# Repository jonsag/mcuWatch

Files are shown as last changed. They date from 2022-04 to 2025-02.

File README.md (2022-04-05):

# mcuWatch

A watch based on an ATmega32P or an ESP8266 module with an RTC clock and a TFT screen  

## Links

### Arduino

[Tutorial on how to use DS3231 RTC Module](https://create.arduino.cc/projecthub/mdraber/tutorial-on-how-to-use-ds3231-rtc-module-e12b38)  
[The ST7735 TFT with arduino](https://www.electronics-lab.com/project/using-st7735-1-8-color-tft-display-arduino/)  
[Arduino DS3231 Real Time Clock With Color TFT](https://www.instructables.com/Arduino-DS3231-Real-time-clock-with-color-TFT/)  

### ESP8266

[ESP8266 pinout reference and how to use GPIO pins](https://microcontrollerslab.com/esp8266-pinout-reference-gpio-pins/)  
[ESP8266 Pinout Reference: Which GPIO pins should you use?](https://randomnerdtutorials.com/esp8266-pinout-reference-gpios/)  
[NodeMCU GPIO with Arduino IDE](https://www.electronicwings.com/nodemcu/nodemcu-gpio-with-arduino-ide)  

[Connecting a 1.77 inch TFT LCD screen to ESP8266](http://gogs.info/blog/2020/03/connecting-177-inch-TFT-LCD-screen-ESP8266/)  
[NodeMCU and 1.8" SPI ST7735 Display](https://www.instructables.com/NodeMCU-and-18-SPI-ST7735-Display/)  
[Interfacing ESP8266 NodeMCU with ST7735 TFT](https://simple-circuit.com/esp8266-nodemcu-st7735s-tft/)  
[ESP8266 NodeMCU Internet Clock with ST7735 TFT](https://simple-circuit.com/esp8266-nodemcu-st7735-tft-internet-clock/)  

### Libraries

[DS3231](https://github.com/NorthernWidget/DS3231)  
[Adafruit GFX Library](https://github.com/adafruit/Adafruit-GFX-Library)  
[Adafruit SSD1306](https://github.com/adafruit/Adafruit_SSD1306)  

#### Tiny/Compact TFT Graphics Library

[Tiny TFT Graphics Library](http://www.technoblogy.com/show?L6I)  

[Compact TFT Graphics Library](http://www.technoblogy.com/show?2LMJ)
[Source](https://github.com/technoblogy/compact-tft-graphics-library)

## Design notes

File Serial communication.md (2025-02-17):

# Serial Communication HowTo

## Find the device

>$ dmesg

    ...
    [256966.875728] usb 1-1.4: ch341-uart converter now attached to ttyUSB0

## CLI software

### picocom

[picocom @ github](https://github.com/npat-efault/picocom)  
[picocom man page](https://linux.die.net/man/8/picocom)  

Connect  
>$ picocom -b 115200 /dev/ttyUSB0 --omap crcrlf  

    picocom v3.1
    ...
    Type [C-a] [C-h] to see available commands
    Terminal ready

Turn on local echo  
> [Ctrl+a] [Ctrl+c]

    *** local echo: yes ***

Exit  

> [Ctrl+a] [Ctrl+x]

    Terminating...
    Thanks for using picocom

### cu

[cu @ github](https://github.com/nedko/cu)  
[cu man page](https://linux.die.net/man/1/cu)  

A simple serial monitor  

>$ cu -l /dev/ttyACM0 -s 9600

Exit
> ~. (tilde dot)  

### screen

[screen man page](https://linux.die.net/man/1/screen)  

Connect  

>$ screen /dev/ttyUSB0 9600

### minicom

[minicom @ github](https://github.com/Distrotech/minicom)  
[minicom man page](https://linux.die.net/man/1/minicom)  

### GUI software

[CuteCom](http://cutecom.sourceforge.net/)  

## ESP-01

### If you have AT firmware, for example an ESP-01

Check for AT firmware  
>AT

    OK

Check version  

>AT+GMR

    AT version:1.7.4.0(May 11 2020 19:13:04)
    SDK version:3.0.4(9532ceb)
    compile time:May 27 2020 10:12:17
    Bin version(Wroom 02):1.7.4
    OK

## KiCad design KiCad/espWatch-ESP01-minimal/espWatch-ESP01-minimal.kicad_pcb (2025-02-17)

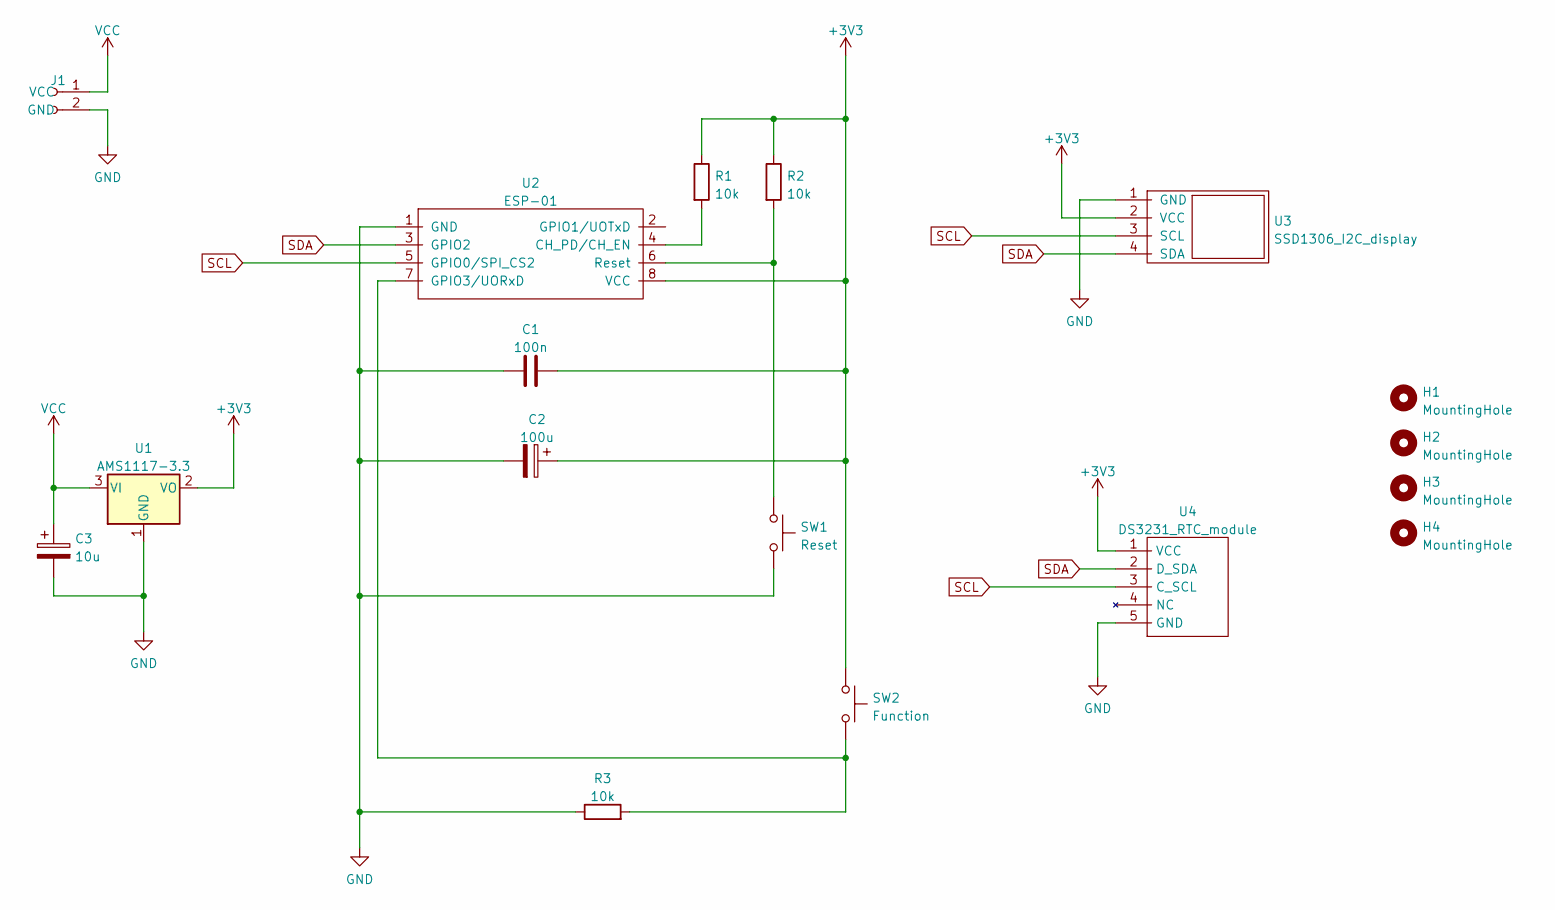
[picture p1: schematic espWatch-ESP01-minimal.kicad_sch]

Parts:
C1: 100n; C_Disc_D3.0mm_W1.6mm_P2.50mm_larg
C2: 100u; CP_Radial_D5.0mm_P2.00mm_larger
C3: 10u; CP_Radial_D5.0mm_P2.00mm_larger
H1, H2, H3, H4: MountingHole; MountingHole_3.2mm_M3
J1: 2-pin_power_input_header; 2-pin_power_input_header_larger_pads
R1, R2, R3: 10k; R_Axial_DIN0207_L6.3mm_D2.5mm_P10.16mm_Horizontal_larger_pa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
SW1: Reset; SW_PUSH_6mm_large
SW2: Function; SW_PUSH_6mm_large
U1: AMS1117-3.3; SOT-223-3_TabPin2
U2: ESP-01; ESP-01_w_pin_socket_large
U3: SSD1306_I2C_display; SSD1306_I2C_0.96_OLED_display_large
U4: DS3231_RTC_module; DS3231_RTC_module_large

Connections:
+3V3: C1.2, C2.1, R1.1, R2.1, SW2.1, U1.2 (VO), U2.8 (VCC), U3.2 (VCC), U4.1 (VCC)
GND: C1.1, C2.2, C3.2, J1.2 (GND), R3.1, SW1.2, U1.1 (GND), U2.1 (GND), U3.1 (GND), U4.5 (GND)
unnamed: R1.2, U2.4 (CH_PD/CH_EN)
unnamed: R2.2, SW1.1, U2.6 (Reset)
unnamed: R3.2, SW2.2, U2.7 (GPIO3/UORxD)
SCL: U2.5 (GPIO0/SPI_CS2), U3.3 (SCL), U4.3 (C_SCL)
SDA: U2.3 (GPIO2), U3.4 (SDA), U4.2 (D_SDA)
VCC: C3.1, J1.1 (VCC), U1.3 (VI)

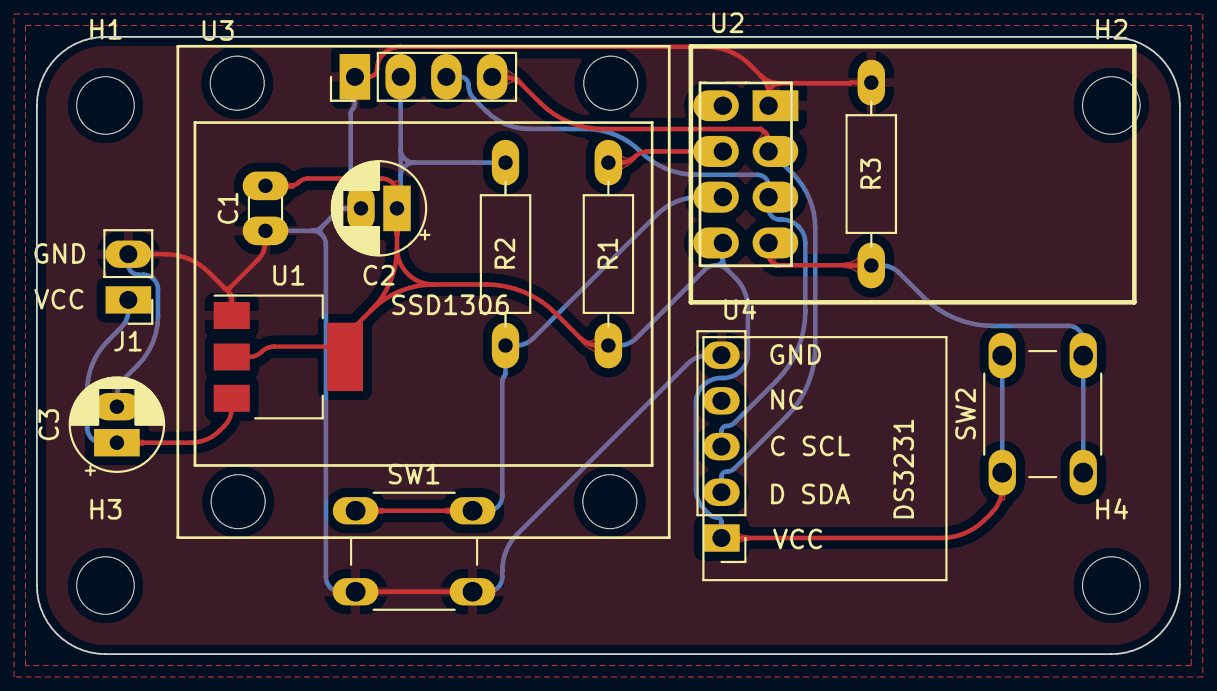
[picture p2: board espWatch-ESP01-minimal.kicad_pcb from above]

Board: 2 copper layers, 63.5 x 34.3 mm, 17 parts (0 on the bottom side), 8 nets.

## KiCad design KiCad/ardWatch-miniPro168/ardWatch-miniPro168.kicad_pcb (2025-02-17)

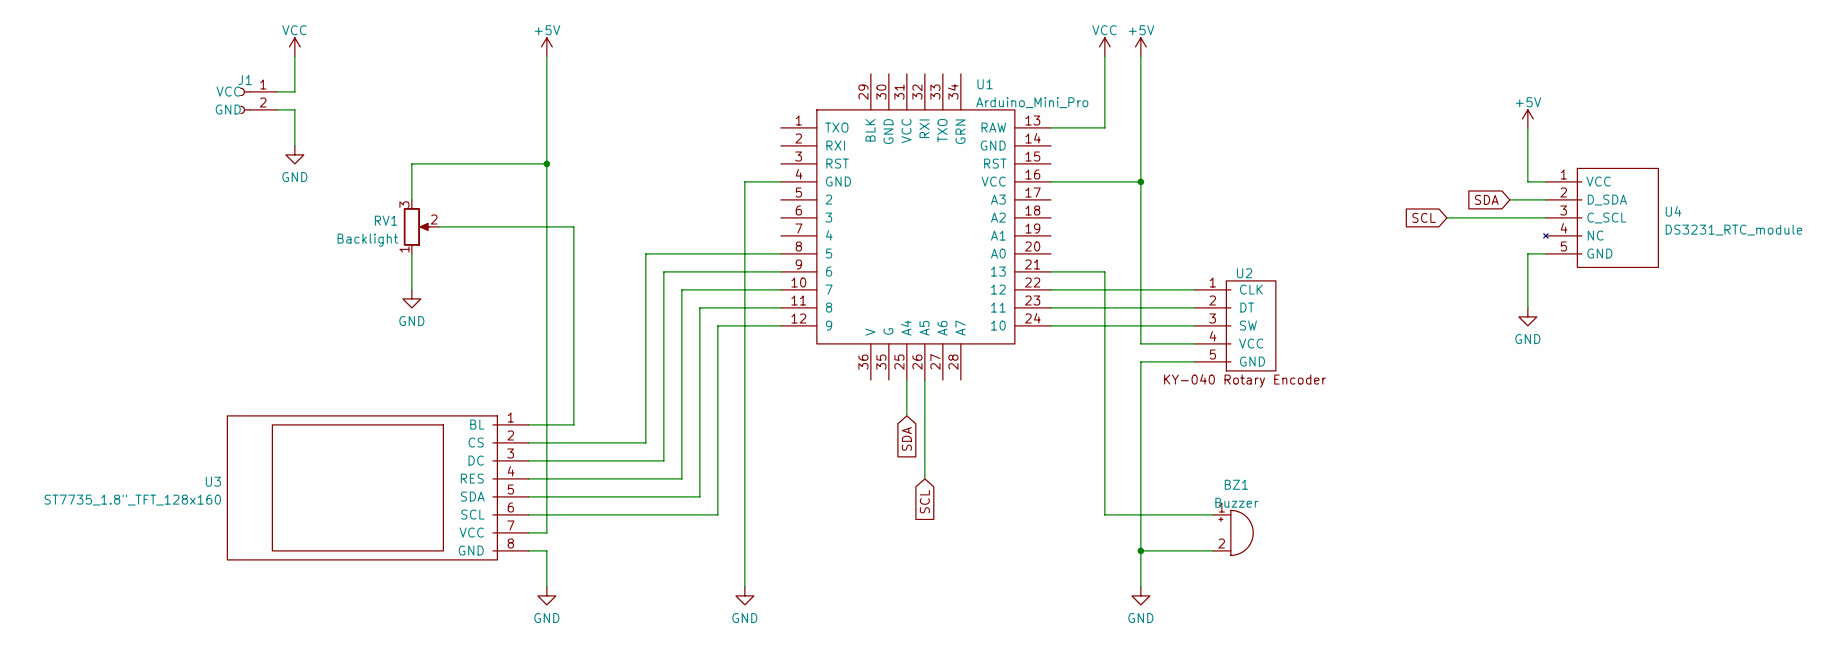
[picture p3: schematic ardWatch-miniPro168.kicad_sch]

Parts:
BZ1: Buzzer; Buzzer_TDK_PS1240P02BT_D12.2mm_H6.5mm_large
J1: 2-pin_power_input_header; 2-pin_power_input_header_larger_pads
RV1: Backlight; Potentiometer_Bourns_3339P_Vertical_large
U1: Arduino_Mini_Pro; Arduino_Pro_Mini_vC_larger_pads
U2: KY-040_Rotary_Encoder; KY-040_rotary_encoder module_w_header_large
U3: ST7735_1.8"_TFT_128x160; ST7735_1.8_TFT_display_128x160_large
U4: DS3231_RTC_module; DS3231_RTC_module_large

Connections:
+5V: RV1.3, U1.16 (VCC), U2.4 (VCC), U3.7 (VCC), U4.1 (VCC)
GND: BZ1.2 (+), J1.2 (GND), RV1.1, U1.4 (GND), U2.5 (GND), U3.8 (GND), U4.5 (GND)
unnamed: U1.8 (5), U3.2 (CS)
unnamed: U1.9 (6), U3.3 (DC)
unnamed: U1.10 (7), U3.4 (RES)
unnamed: U1.11 (8), U3.5 (SDA)
unnamed: U1.12 (9), U3.6 (SCL)
unnamed: BZ1.1 (-), U1.21 (13)
unnamed: U1.22 (12), U2.1 (CLK)
unnamed: U1.23 (11), U2.2 (DT)
unnamed: U1.24 (10), U2.3 (SW)
unnamed: RV1.2, U3.1 (BL)
SCL: U1.26 (A5), U4.3 (C_SCL)
SDA: U1.25 (A4), U4.2 (D_SDA)
VCC: J1.1 (VCC), U1.13 (RAW)

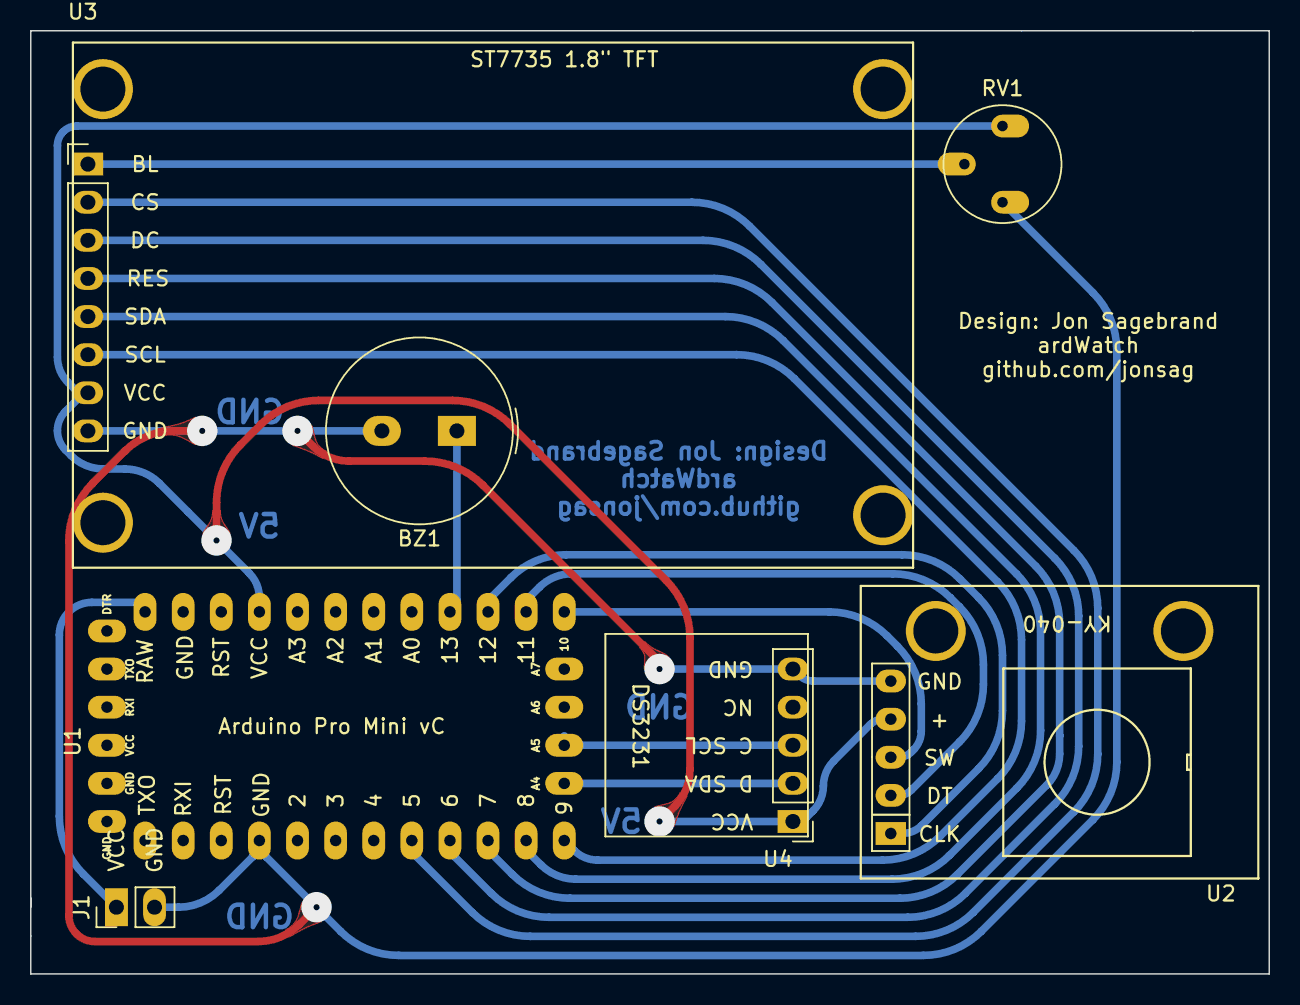
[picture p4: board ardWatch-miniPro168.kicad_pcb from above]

Board: 2 copper layers, 82.5 x 62.9 mm, 7 parts (0 on the bottom side), 15 nets.

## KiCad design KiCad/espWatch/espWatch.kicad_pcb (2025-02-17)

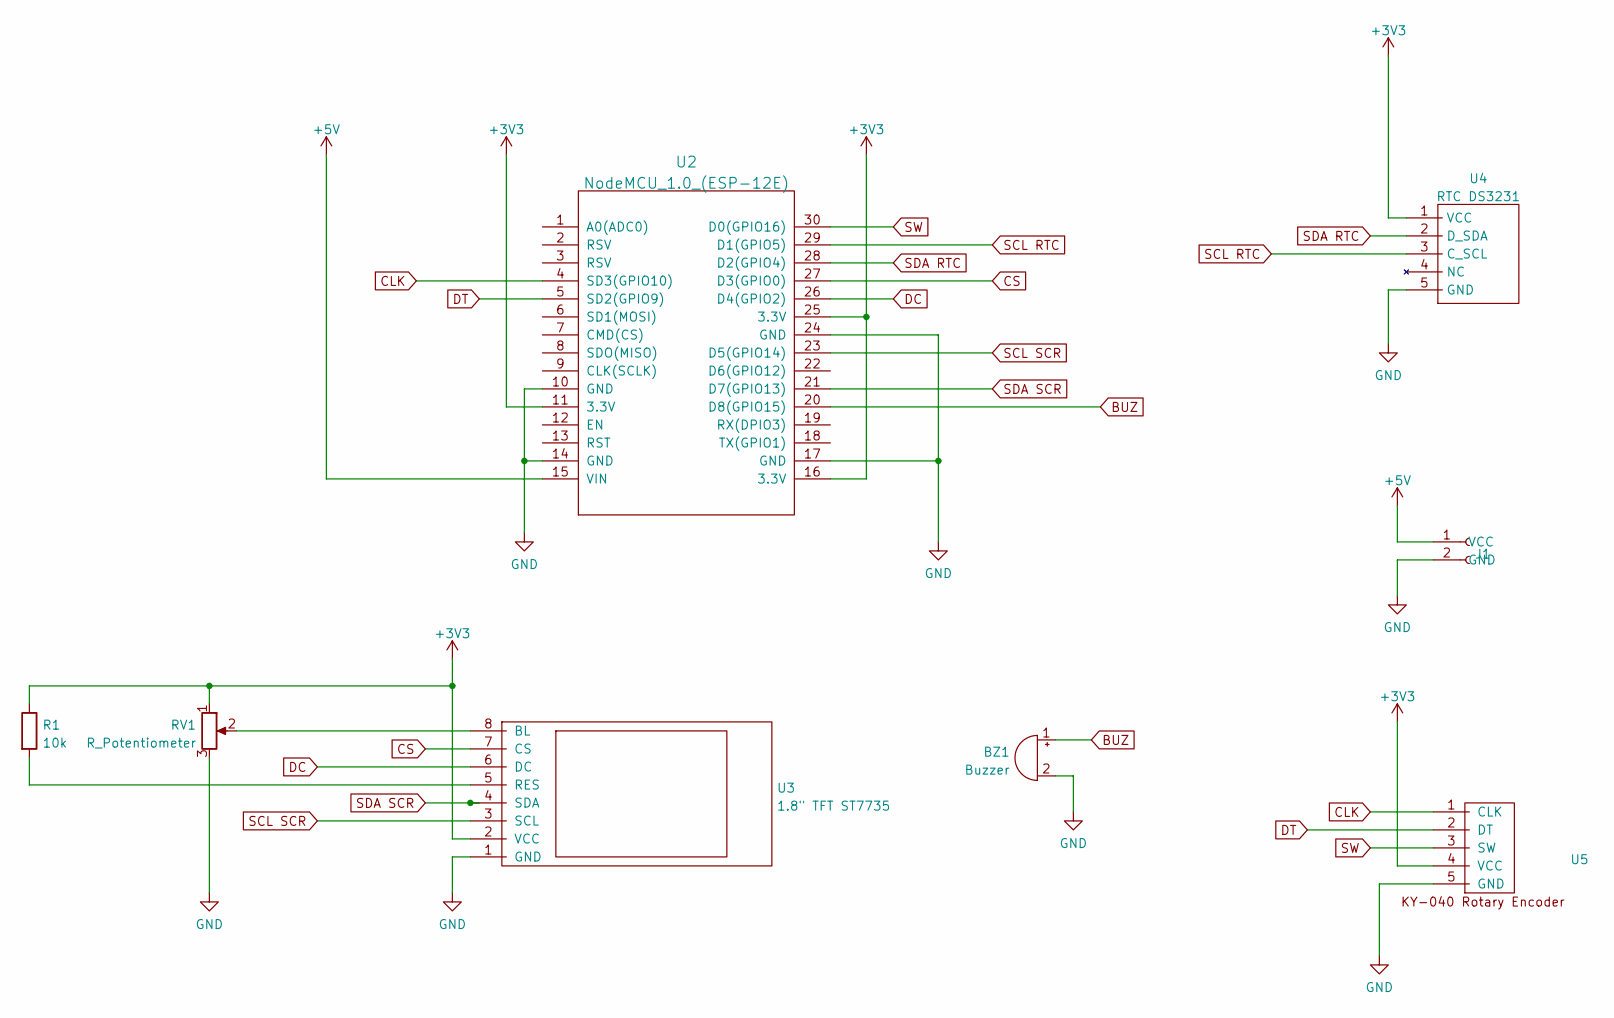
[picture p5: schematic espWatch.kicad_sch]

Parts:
BZ1: Buzzer; Buzzer_TDK_PS1240P02BT_D12.2mm_H6.5mm_large
J1: 2-pin_power_input_header; 2-pin_power_input_header_larger_pads
R1: 10k; R_Axial_DIN0207_L6.3mm_D2.5mm_P10.16mm_Horizontal_larger_pa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
RV1: R_Potentiometer; Potentiometer_Bourns_3339P_Vertical_large
U2: NodeMCU_1.0_(ESP-12E); NodeMCU-LoLinV3_w_pinsockets_large
U3: 1.8" TFT ST7735; ST7735_1.8_TFT_display_128x160_large
U4: RTC DS3231; DS3231_RTC_module_large
U5: KY-040_Rotary_Encoder; KY-040_rotary_encoder module_w_header_large

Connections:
+3V3: R1.1, RV1.1, U2.11 (3.3V), U2.16 (3.3V), U2.25 (3.3V), U3.2 (VCC), U4.1 (VCC), U5.4 (VCC)
+5V: J1.1 (VCC), U2.15 (VIN)
BUZ: BZ1.1 (-), U2.20 (D8(GPIO15))
CLK: U2.4 (SD3(GPIO10)), U5.1 (CLK)
CS: U2.27 (D3(GPIO0)), U3.7 (CS)
DC: U2.26 (D4(GPIO2)), U3.6 (DC)
DT: U2.5 (SD2(GPIO9)), U5.2 (DT)
GND: BZ1.2 (+), J1.2 (GND), RV1.3, U2.10 (GND), U2.14 (GND), U2.17 (GND), U2.24 (GND), U3.1 (GND), U4.5 (GND), U5.5 (GND)
unnamed: R1.2, U3.5 (RES)
unnamed: RV1.2, U3.8 (BL)
SCL RTC: U2.29 (D1(GPIO5)), U4.3 (C_SCL)
SCL SCR: U2.23 (D5(GPIO14)), U3.3 (SCL)
SDA RTC: U2.28 (D2(GPIO4)), U4.2 (D_SDA)
SDA SCR: U2.21 (D7(GPIO13)), U3.4 (SDA)
SW: U2.30 (D0(GPIO16)), U5.3 (SW)

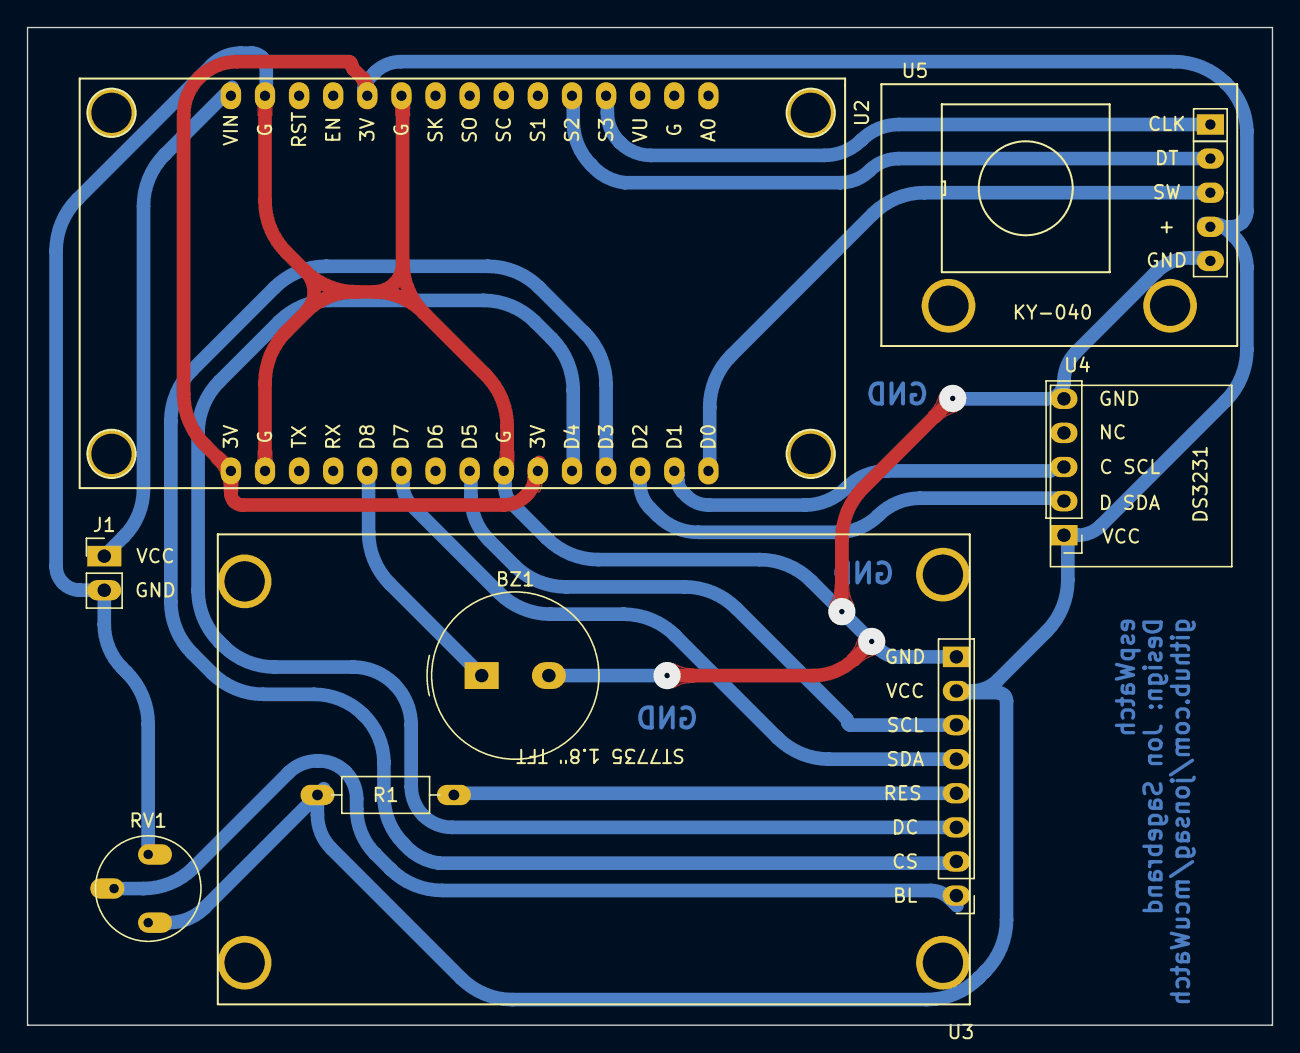
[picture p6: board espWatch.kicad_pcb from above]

Board: 2 copper layers, 92.7 x 74.3 mm, 8 parts (0 on the bottom side), 15 nets.

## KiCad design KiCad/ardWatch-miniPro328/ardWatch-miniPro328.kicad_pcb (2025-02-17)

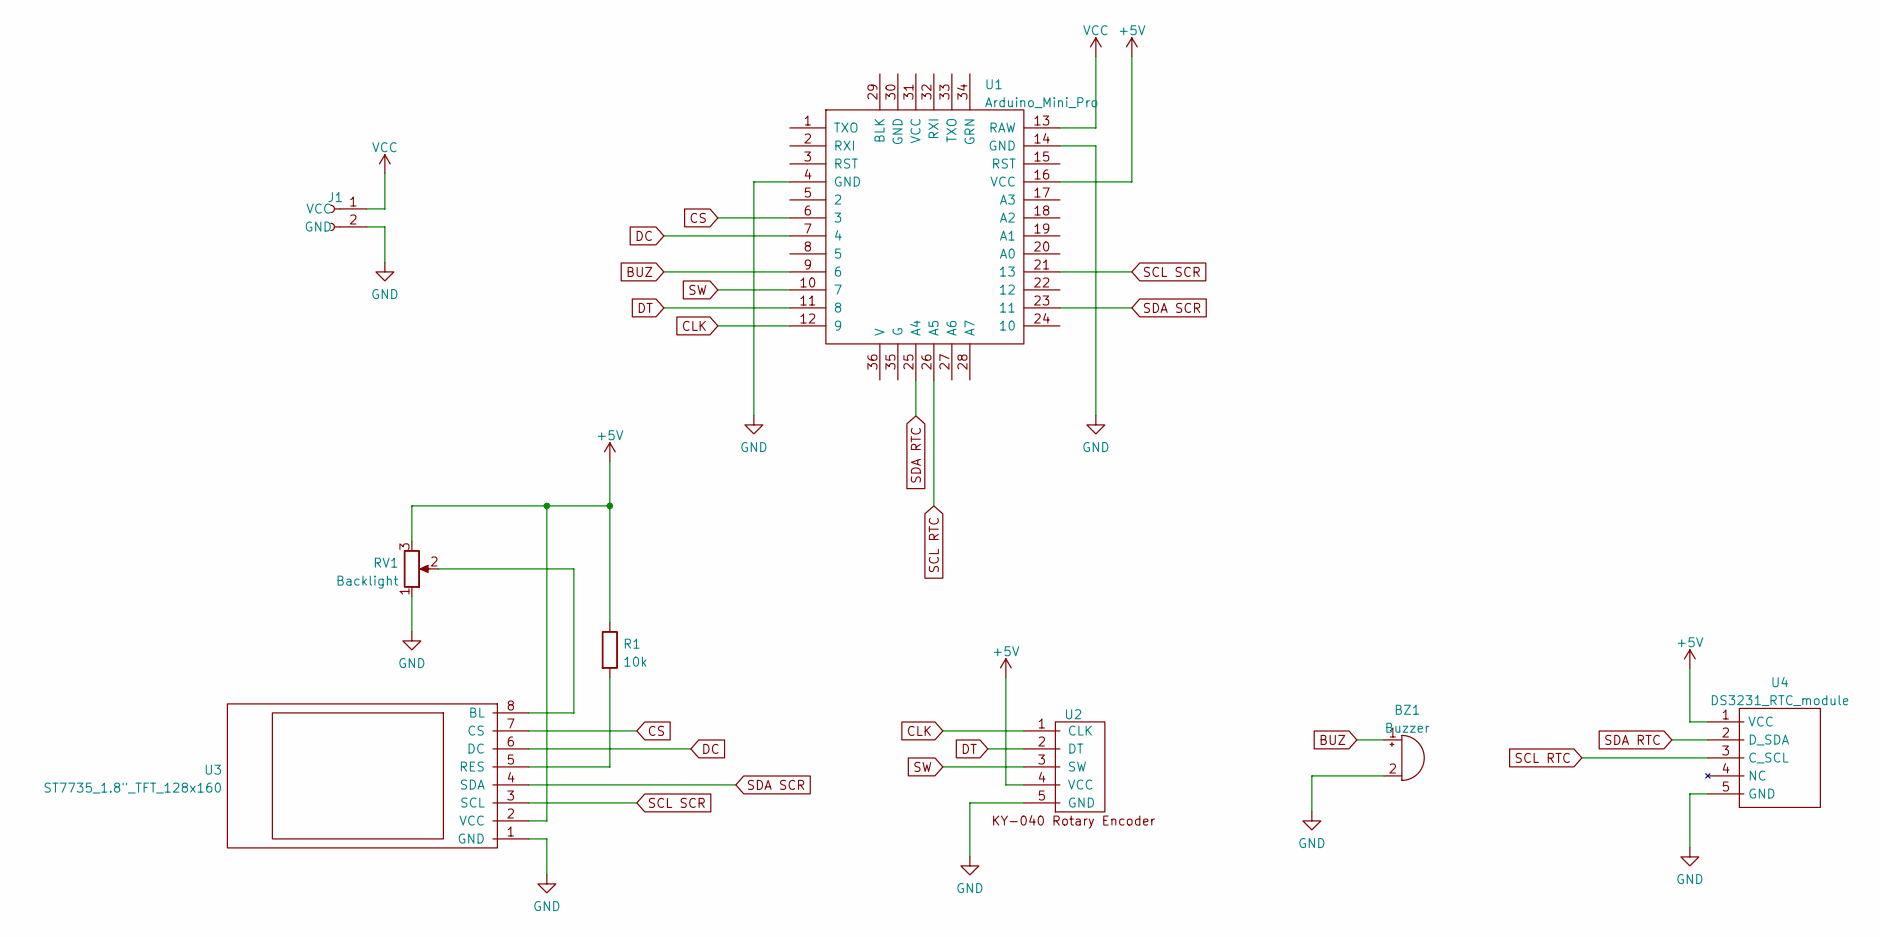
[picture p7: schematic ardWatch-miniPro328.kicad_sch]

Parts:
BZ1: Buzzer; Buzzer_TDK_PS1240P02BT_D12.2mm_H6.5mm_large
J1: 2-pin_power_input_header
R1: 10k; R_Axial_DIN0207_L6.3mm_D2.5mm_P10.16mm_Horizontal_larger_pa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
RV1: Backlight; Potentiometer_Bourns_3339P_Vertical_large
U1: Arduino_Mini_Pro; Arduino_Pro_Mini_vA_sides_n_A4,A5_large
U2: KY-040_Rotary_Encoder; KY-040_rotary_encoder module_w_header_large
U3: ST7735_1.8"_TFT_128x160; ST7735_1.8_TFT_display_128x160_large
U4: DS3231_RTC_module; DS3231_RTC_module_large

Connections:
+5V: R1.1, RV1.3, U1.16 (VCC), U2.4 (VCC), U3.2 (VCC), U4.1 (VCC)
BUZ: BZ1.1 (-), U1.9 (6)
CLK: U1.12 (9), U2.1 (CLK)
CS: U1.6 (3), U3.7 (CS)
DC: U1.7 (4), U3.6 (DC)
DT: U1.11 (8), U2.2 (DT)
GND: BZ1.2 (+), J1.2 (GND), RV1.1, U1.4 (GND), U1.14 (GND), U2.5 (GND), U3.1 (GND), U4.5 (GND)
unnamed: R1.2, U3.5 (RES)
unnamed: RV1.2, U3.8 (BL)
SCL RTC: U1.26 (A5), U4.3 (C_SCL)
SCL SCR: U1.21 (13), U3.3 (SCL)
SDA RTC: U1.25 (A4), U4.2 (D_SDA)
SDA SCR: U1.23 (11), U3.4 (SDA)
SW: U1.10 (7), U2.3 (SW)
VCC: J1.1 (VCC), U1.13 (RAW)

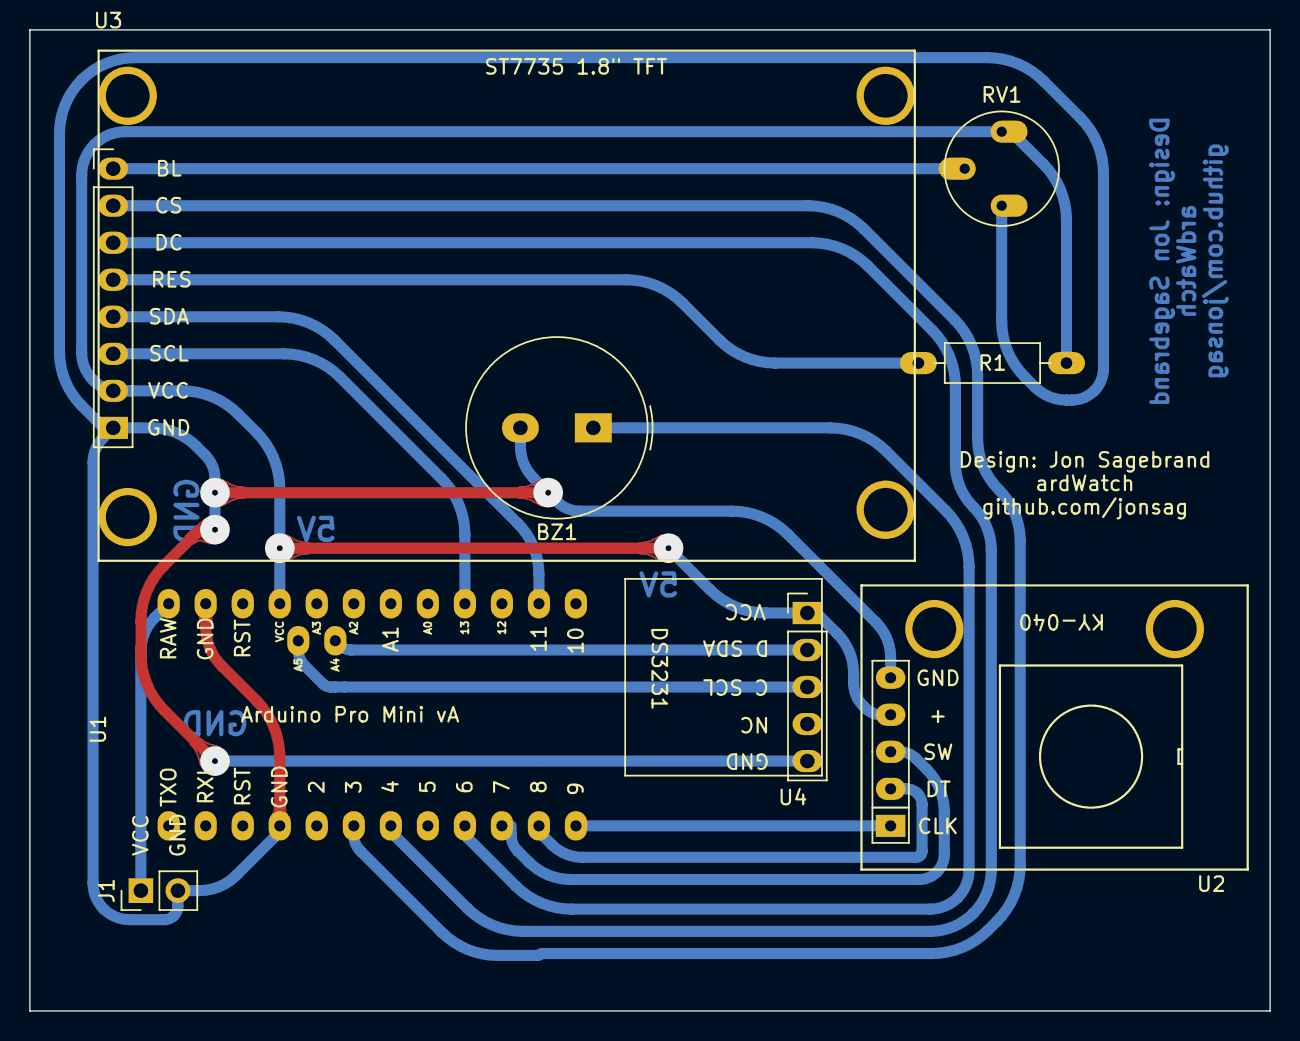
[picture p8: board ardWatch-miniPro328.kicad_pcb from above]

Board: 2 copper layers, 85.1 x 67.3 mm, 8 parts (0 on the bottom side), 15 nets.

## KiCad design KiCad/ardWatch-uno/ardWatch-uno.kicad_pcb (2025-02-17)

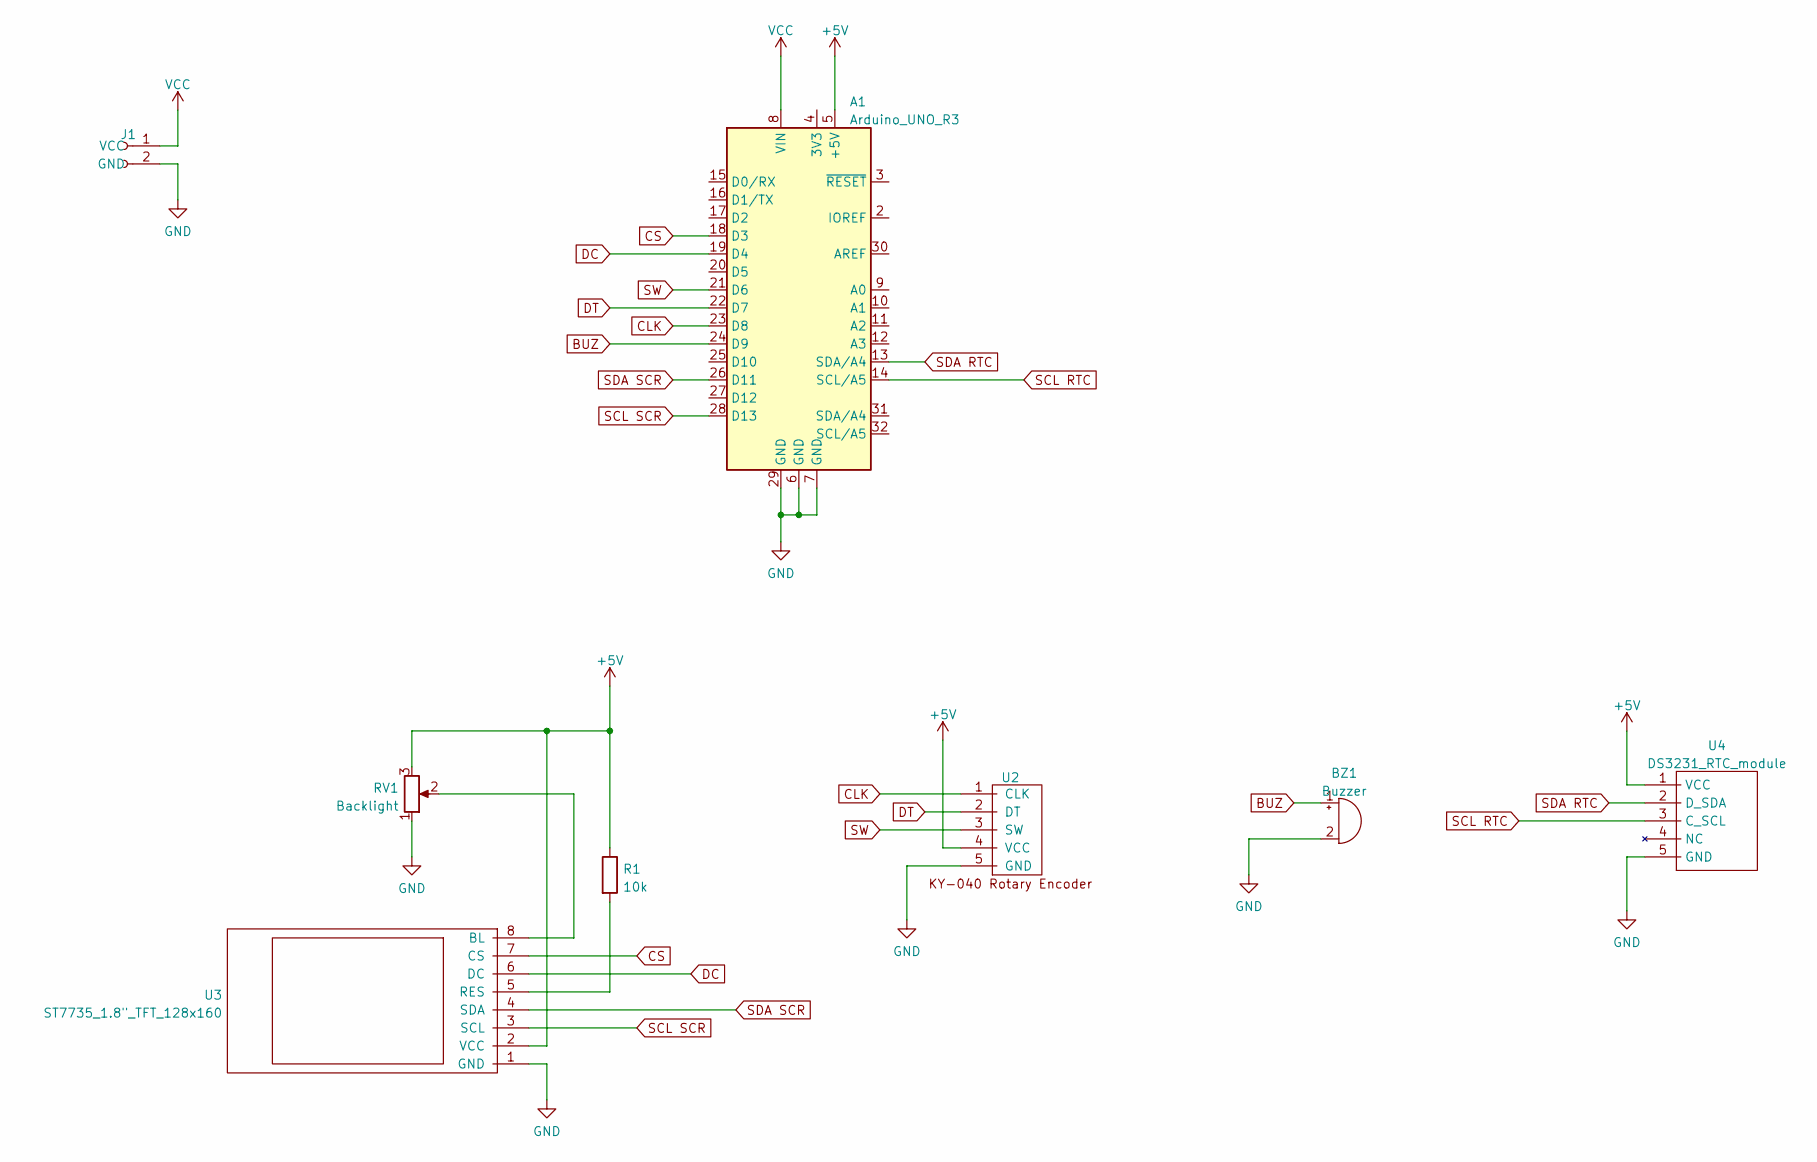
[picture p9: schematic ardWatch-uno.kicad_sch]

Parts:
A1: Arduino_UNO_R3; Arduino_UNO_R3_shield_large
BZ1: Buzzer; Buzzer_TDK_PS1240P02BT_D12.2mm_H6.5mm_large
J1: 2-pin_power_input_header
R1: 10k; R_Axial_DIN0207_L6.3mm_D2.5mm_P10.16mm_Horizontal_larger_pa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
RV1: Backlight; Potentiometer_Bourns_3339P_Vertical_large
U2: KY-040_Rotary_Encoder; KY-040_rotary_encoder module_w_header_large
U3: ST7735_1.8"_TFT_128x160; ST7735_1.8_TFT_display_128x160_large
U4: DS3231_RTC_module; DS3231_RTC_module_large

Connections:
+5V: A1.5 (+5V), R1.1, RV1.3, U2.4 (VCC), U3.2 (VCC), U4.1 (VCC)
BUZ: A1.24 (D9), BZ1.1 (-)
CLK: A1.23 (D8), U2.1 (CLK)
CS: A1.18 (D3), U3.7 (CS)
DC: A1.19 (D4), U3.6 (DC)
DT: A1.22 (D7), U2.2 (DT)
GND: A1.6 (GND), A1.7 (GND), A1.29 (GND), BZ1.2 (+), J1.2 (GND), RV1.1, U2.5 (GND), U3.1 (GND), U4.5 (GND)
unnamed: R1.2, U3.5 (RES)
unnamed: RV1.2, U3.8 (BL)
SCL RTC: A1.14 (SCL/A5), U4.3 (C_SCL)
SCL SCR: A1.28 (D13), U3.3 (SCL)
SDA RTC: A1.13 (SDA/A4), U4.2 (D_SDA)
SDA SCR: A1.26 (D11), U3.4 (SDA)
SW: A1.21 (D6), U2.3 (SW)
VCC: A1.8 (VIN), J1.1 (VCC)

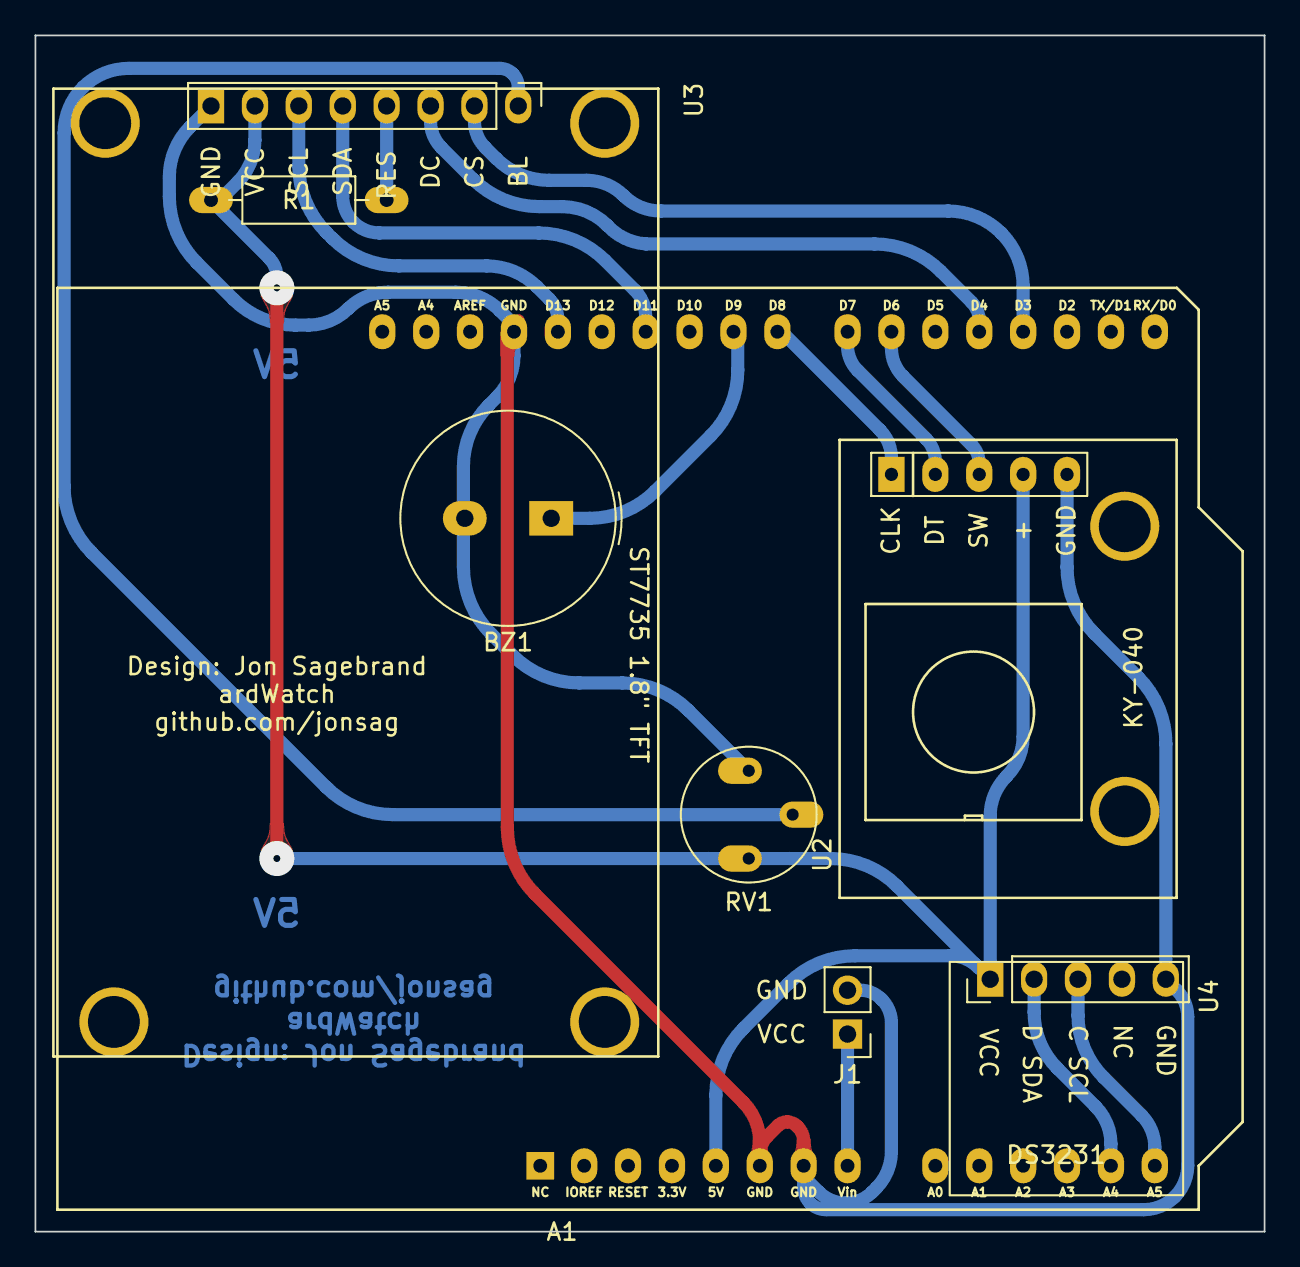
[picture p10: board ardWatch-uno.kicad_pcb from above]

Board: 2 copper layers, 71.1 x 69.2 mm, 8 parts (0 on the bottom side), 15 nets.

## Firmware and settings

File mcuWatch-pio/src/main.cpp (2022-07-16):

#include <Arduino.h>

#include "config.h"
#include "RTCf.h"

#include "screenDrawf.h"
#include "webServer.h"
#include "NTPf.h"
#include "EEPROMf.h"

// Setup##############################****************

void setup()
{
  // ############################## start serial
#if DEBUG || INFO
  Serial.begin(serialSpeed); // start the serial port

  Serial.setTimeout(serialTimeout);

  debugMessln();
  debugMessln("mcuWatch");
  debugMessln();

#endif // DEBUG || INFO

  // ############################## start wire
  debugMessln("Starting wire ...");
  Wire.begin();

  debugMessln();

  // ############################## start screen
  debugMessln("Initializing display ...");

  myScreen.initR(INITR_BLACKTAB);

  debugMessln("Initialized");
  debugMess("Screen size: ");
  debugMess(myScreen.width());
  debugMess("x");
  debugMessln(myScreen.height());
  debugMessln();

  clearScreen();

  // ############################## start RTC
  debugMessln("Starting RTC ...");

  printStartMess("RTC ...", 1);

  if (!rtc.begin())
  {
    debugMessln("Couldn't find RTC");
  }
  else
  {
    debugMessln("RTC found");
  }

  debugMessln();

  clearScreen();

  // ############################## start and connect wifi
  debugMessln("Starting and connecting wifi ...");

  printStartMess("Connecting ...", 1);

  startTime = millis();
  WiFi.mode(WIFI_STA);
  WiFi.begin(STASSID, STAPSK);

  while (WiFi.status() != WL_CONNECTED && (millis() - startTime) <= wifiTimeout) // wait for connection
  {
    debugMess(".");
    delay(500);
    // static uint16_t counter = 0;
    // counter++;
    // if (counter % 30 == 0)
  }

  WiFi.setAutoReconnect(true);
  WiFi.persistent(true);

  debugMessln();

  clearScreen();

  if (WiFi.status() != WL_CONNECTED)
  {
    infoMessln("ERROR: Could not connect");
  }
  else
  {
    infoMess("Connected to ");
    infoMessln(ssid);
    infoMess("IP address: ");
    infoMessln(WiFi.localIP());

    printIP();
    delay(2000);
    clearScreen();
  }
  infoMessln();

  // ############################## start web server
  startWebServer();

  currentMillis = millis();

  // ############################## show info
  infoMessln("Set time with YYMMDDwhhmmssx, ");
  infoMessln("where YY = Year (ex. 20 for 2020)");
  infoMessln("      MM = Month (ex. 04 for April)");
  infoMessln("      DD = Day of month (ex. 09 for 9th)");
  infoMessln("      w  = Day of week from 1 to 7, 1 = Monday (ex. 4 for Thursday)");
  infoMessln("      hh = hours in 24h format (ex. 09 for 9AM or 21 for 9PM)");
  infoMessln("      mm = minutes (ex. 02)");
  infoMessln("      ss = seconds (ex. 42)");
  infoMessln("End with 'x'");
  infoMessln("Example for input : 2004094090242x");
  infoMessln();

  // ############################## set up screen
  debugMessln("Clearing screen ...");
  clearScreen();

  debugMessln();

  // ############################## start NTP client
  debugMessln("Starting NTP client ...");

  printStartMess("Starting NTP ...", 1);

  timeClient.begin();                   // initialize a NTP client to get time
  timeClient.setTimeOffset(timeOffset); // set offset time

  clearScreen();

  debugMessln();

#if DEBUG
  debugMessln("Drawing help lines ...");
  debugMessln();
  helpLines();

  debugMessln();

#endif // DEBUG

  // ############################## get time and temp from RTC
  debugMessln("Getting time...");
  now = RTCTimeNow();

  debugMessln("Getting temperature...");
  temperature = RTCTempNow();

  prettyPrint(now, temperature);
  oldEpoch = now;

  lastRTCCheckMillis = currentMillis;

  updateScreen(now, temperature);

  // ############################## initial NTP check
  if (WiFi.status() != WL_CONNECTED)
  {
    drawText(myScreen.width() / XSplits * wifiStatusXPos - wifiStatusString.length() / 2.0 * pixX * wifiStatusSize, // x
             myScreen.height() / YSplits * wifiStatusYPos,                                                          // y
             wifiStatusSize,                                                                                        // size
             wifiStatusDownCol,                                                                                     // colour
             wifiStatusString);

    debugMessln("Not connected");
  }
  else
  {
    drawText(myScreen.width() / XSplits * wifiStatusXPos - wifiStatusString.length() / 2.0 * pixX * wifiStatusSize, // x
             myScreen.height() / YSplits * wifiStatusYPos,                                                          // y
             wifiStatusSize,                                                                                        // size
             wifiStatusOKCol,                                                                                       // colour
             wifiStatusString);

    checkNetworkTime();
  }

  lastNTPCheckMillis = currentMillis;

  // ############################## finished with setup
  debugMessln("Start finished!");
  debugMessln("Now entering main loop ...");
  debugMessln();
}

// ############################## Main

void updateOutput()
{
  RTCtest(now);

  prettyPrint(now, temperature);

  updateScreen(now, temperature);
}

void getRTCData()
{
  debugMessln("Getting time...");
  now = RTCTimeNow();

  debugMessln("Getting temperature...");
  temperature = RTCTempNow();
}

void loop()
{
  currentMillis = millis();

  setTime(); // check for keyboard input

  server.handleClient();
  MDNS.update();

// ############################## if in debug mode, only check every interval
#if DEBUG
  if (currentMillis - lastRTCCheckMillis >= RTCCheckInterval)
  {
    getRTCData();
    updateOutput();
    lastRTCCheckMillis = currentMillis;
  }

// ############################## otherwise check every time, then see if a second have passed
#else
  getRTCData();
  if (now.getEpoch() != oldEpoch.getEpoch())
  {
    updateOutput();
    oldEpoch = now;
  }

#endif

  // ############################## update from NTP
  if (currentMillis - lastNTPCheckMillis >= NTPCheckInterval)
  {
    // erase drift from screen
    fillRectangle(myScreen.width() / XSplits * driftXPos - 10 / 2.0 * pixX * driftSize, // x
                  myScreen.height() / YSplits * driftYPos,                              // y
                  10 * pixX * driftSize,                                                // width
                  pixY * driftSize,                                                     // height
                  bgCol);

    if (WiFi.status() != WL_CONNECTED)
    {
      drawText(myScreen.width() / XSplits * wifiStatusXPos - wifiStatusString.length() / 2.0 * pixX * wifiStatusSize, // x
               myScreen.height() / YSplits * wifiStatusYPos,                                                          // y
               wifiStatusSize,                                                                                        // size
               wifiStatusDownCol,                                                                                     // colour
               wifiStatusString);

      debugMessln("Not connected");
    }
    else
    {
      drawText(myScreen.width() / XSplits * wifiStatusXPos - wifiStatusString.length() / 2.0 * pixX * wifiStatusSize, // x
               myScreen.height() / YSplits * wifiStatusYPos,                                                          // y
               wifiStatusSize,                                                                                        // size
               wifiStatusOKCol,                                                                                       // colour
               wifiStatusString);

      checkNetworkTime();
    }

    lastNTPCheckMillis = currentMillis;
  }
}

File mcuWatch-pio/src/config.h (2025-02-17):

#include <Wire.h>

/**********
 * Debug
 **********/
#define DEBUG 0 // debugMess is off when 0
#define INFO 1

#if DEBUG
#define debugMess(x) Serial.print(x)
#define debugMessln(x) Serial.println(x)

#else
#define debugMess(x)
#define debugMessln(x)
#endif

#if INFO || DEBUG
#define infoMess(x) Serial.print(x)
#define infoMessln(x) Serial.println(x)
#else
#define infoMess(x)
#define infoMessln(x)
#endif

/*
SPI (ST7735)
Function    Screen pin  Mini        Uno         Mega        ESP8266     ESP-01      Comment
-----       -----       -----       -----       -----       -----       -----       -----
SCK         3           D13*)       D13*)       D52*)       D5/GPIO14*)             SCL, HSCLK, SPI Clock, Hardware SPI clk
SDA         4           D11*)       D11*)       D51*)       D7/GPIO13*)             SPI Data, MOSI, HMOSI, data to screen
RES         5           D5          D5          D5          D6/GPIO12               RST, MISO, HMISO, screen reset
DC          6           D4          D4          D4          D4/GPIO2                Register Select, labelled as DC in Adafruit code
CS          7           D3          D3          D3          D3/GPIO0                Chip Select, defined as Slave Select in SPI

I2C (RTC and SSD1306)
Function    RTC         Screen      Uno, Mini   Mega        ESP8266     ESP-01
-----       -----       -----       -----       -----       -----       -----
Address     0x68        0x3C
SDA         2                       A4*)         20*)      D2/GPIO4*)  3/GPIO2
SCL         3                       A5*)         21*)      D1/GPIO5*)  5/GPIO0
  oldNow = now;

Rotary encoder
Function                Arduino 168 Arduino 328 ESP8266     ESP-01
-----                   -----       -----       -----       -----
CLK                                 D9
DT                                  D8
SW                                  D7

Buzzer
Function                Arduino 168 Arduino 328 ESP8266     ESP-01
-----                   -----       -----       -----       -----
+                                   D6          D8/GPIO15

*) Must be these pins as they are set in firmware/hardware

Find macro definitions:
$ grep board= `find ~/.platformio/ -name boards.txt` | cut -f2 -d= | sort -u
*/

/**********
 * Pins
 **********/
// #define i2cSDA D2
// #define i2cSCK D1

#define tftSCK D5
#define tftSDA D7

#define tftRES D6
#define tftDC D4 // GPIO2, TFT display SPI chip select pin
#define tftCS D3 // GPIO0, TFT display data/command select pin

#define rotCLK SD3 // GPIO10
#define rotDT SD2  // GPIO9
#define rotSW D0   // GPIO16

#define buz D8 // GPIO2

/**********
 * TFT screen
 **********/
#include <Adafruit_GFX.h>
#include <Adafruit_ST7735.h>

Adafruit_ST7735 myScreen = Adafruit_ST7735(tftCS, tftDC, tftRES);

// colours
#define bgCol ST77XX_BLACK

#define helpLineCol ST77XX_GREEN

#

/*
#define colBla ST77XX_BLACK   // 0x0000
#define colWhi ST77XX_WHITE   // 0xFFFF
#define colRed ST77XX_RED     // 0xF800
#define colGre ST77XX_GREEN   // 0x07E0
#define colBlu ST77XX_BLUE    // 0x001F
#define colCya ST77XX_CYAN    // 0x07FF
#define colMag ST77XX_MAGENTA // 0xF81F
#define colYel ST77XX_YELLOW  // 0xFFE0
#define colOra ST77XX_ORANGE  // 0xFC00
*/

// sizes
#define startCol ST77XX_WHITE
#define startSize 1

// positions
#define XSplits 4 // split screen vertically, this is used below for positions
#define YSplits 8 // split screen horizontally, this is used below for positions

#define dateCol ST77XX_YELLOW
#define dateSize 1
#define dateXPos 2
#define dateYPos 1

#define timeCol ST77XX_GREEN
#define timeSize 4
#define timeNowXPos 2
#define timeNowYPos 2

#define tempCol ST77XX_YELLOW
#define tempNowSize 3
#define tempNowXPos 2
#define tempNowYPos 4

#define tempSize 2

#define maxTempCol ST77XX_RED
#define tempMaxXPos 3
#define tempMaxYPos 6

#define minTempCol ST77XX_BLUE
#define tempMinXPos 1
#define tempMinYPos 6

#define wifiStatusSize 1
#define wifiStatusOKCol ST77XX_GREEN
#define wifiStatusDownCol ST77XX_RED
#define wifiStatusXPos 1
#define wifiStatusYPos 0
const String wifiStatusString = "WiFi";

#define driftSize 1
#define driftCol ST77XX_GREEN
#define driftXPos 3
#define driftYPos 0

// compensations
#define timeXOffs 2

// font, how many pixels are the font built of
#define pixX 6
#define pixY 8

/**********
 * RTC
 **********/
/*
RTC module from above
------------
| 5 GND     |
| 4 NC      |
| 3 C SCL   |
| 2 D SDA   |
| 1 VCC     |
------------
*/

#include <Sodaq_DS3231.h>

const int hourOffs = 0;

DateTime now;
DateTime oldNow;
DateTime oldEpoch;

float temperature;
float oldTemp;

float maxTemp = -100.0;
float minTemp = 100.0;

DateTime maxTempNow;
DateTime minTempNow;

byte year;
byte month;
byte date;
byte dOW;
byte hour;
byte minute;
byte second;

const char *monthName[12] = {
    "Jan", "Feb", "Mar", "Apr", "May", "Jun",
    "Jul", "Aug", "Sep", "Oct", "Nov", "Dec"};

const char *dayName[7] = {
    "Mon", "Tue", "Wed", "Thu", "Fri", "Sat", "Sun"};
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

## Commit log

2022-03-26 renames, code
    [ardWatch-miniPro168.kicad_pcb, ardWatch-miniPro168.kicad_sch, ardWatch.kicad_pcb]
2022-04-07 finally prints text
2022-04-07 print formatted time
2022-04-09 revised pcb
    [ardWatch-miniPro328.kicad_pcb, ardWatch-miniPro328.kicad_sch]
2022-04-09 forgot Wire.begin()
2022-04-10 new 328 pcb
    [ardWatch-miniPro328.kicad_pcb, ardWatch-miniPro328.kicad_sch]
2022-04-11 pcb and pin config
    [ardWatch-miniPro328.kicad_sch, espWatch.kicad_pcb, espWatch.kicad_sch]
2022-04-11 moverd rtc
    [espWatch.kicad_pcb]
2022-04-11 added power input header
    [espWatch.kicad_pcb, espWatch.kicad_sch]
2022-04-11 new layout
    [ardWatch-miniPro328.kicad_pcb, ardWatch-miniPro328.kicad_sch]
2022-04-11 uno version
    [ardWatch-uno.kicad_pcb, ardWatch-uno.kicad_sch]
2022-04-12 new schematics for esp
    [espWatch.kicad_pcb, espWatch.kicad_sch]
2022-04-16 quick fix for hour offset
    [config.h]
2022-04-18 esp32 experiment
2022-04-18 not working on nodemcu
    [config.h]
2022-04-18 RTCtest prints fine
2022-04-29 prints IP at start
2022-05-06 esp01 pcb
    [espWatch-ESP01.kicad_pcb]
2022-05-06 better pcb
    [espWatch-ESP01.kicad_pcb, espWatch-ESP01.kicad_sch]
2022-06-13 esp01 minimal
    [ardWatch-miniPro328.kicad_sch, espWatch-ESP01-minimal.kicad_pcb, espWatch-ESP01-minimal.kicad_sch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]
2022-07-12 new pcb
    [espWatch.kicad_pcb, espWatch.kicad_sch]
2022-07-16 shows wifi status and drift
    [NTPf.h, config.h, main.cpp]
2025-02-17 kicad v8
    [ardWatch-miniPro168.kicad_pcb, ardWatch-miniPro168.kicad_sch, ardWatch-miniPro328.kicad_pcb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]
